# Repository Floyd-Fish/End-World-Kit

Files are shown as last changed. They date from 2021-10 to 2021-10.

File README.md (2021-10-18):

# End-World-Kit
末世生存装置——帮助你在废土世界中(比如核战争后的世界)更好地生存的传感器平台

## 安装的传感器

| 型号 | 描述 |
| ----- | --- |
| BMP280 | 温度、气压(可据此推算海拔) |
| SHT30D | 温度与湿度 |
| BH1750 | 数字光强度 |
| CCS811 | 二氧化碳与挥发性有机物 |
| MPU6050 | 6轴加速度与倾角传感器(附带温度) |
| S12SD | 紫外线强度 |
| [Open-Radiation-Detector](https://hackaday.io/project/27508-open-radiation-detector) | 辐射检测 |
| ATGM336H | 北斗+GPS双模定位模组(**未安装测试**) |

## 工程组织

原理图&PCB使用Kicad 5.1.9设计，4层板
软件使用Visual GDB+Arduino框架为ESP32开发，使用了很多第三方库

# English README

End World-Kit --- A sensor platform which makes your living more easier in the Wastland world (eg: a world after nuclear war)

## Sensors on board:

| Model | Description |
| ----- | --- |
| BMP280 | Temperature and Pressure (and altitude)|
| SHT30D | Temperature and Humidity |
| BH1750 | Digital Light (lux) |
| CCS811 | CO2 and TVOC |
| MPU6050 | 6-axis Gyro (and Temperature) |
| S12SD | UV Light Level |
| [Open-Radiation-Detector](https://hackaday.io/project/27508-open-radiation-detector) | Radiation Detect |
| ATGM336H | BD+GPS (**Not Tested yet**) |

## Project Structure

Schematic & PCB were designed using Kicad 5.1.9, 4-Layer PCB.

ESP32 was deved using Visual GDB & Arduino Framework, lots of 3rd-party libraries were used.

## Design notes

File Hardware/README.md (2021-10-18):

# Hardware

Developed by KiCad 5.1.9, Please Note it's not compatible with the newest KiCad Version 6.0.  

# Note

To save materials, I put 2 boards together so u need to cut them into 2 pieces.

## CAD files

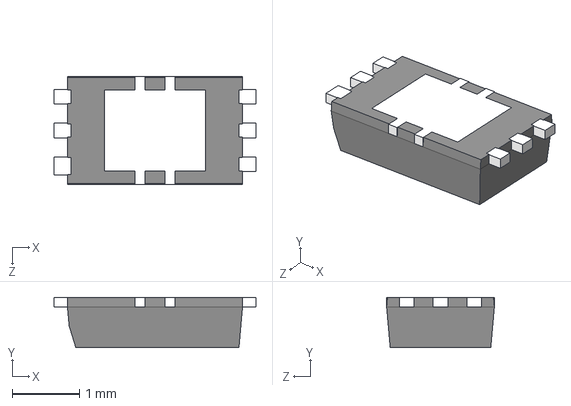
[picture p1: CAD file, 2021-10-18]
Hardware/End_World_Kit_V3.0/3D/BH1750FVI-TR.stp
3.00 x 0.75 x 1.60 mm

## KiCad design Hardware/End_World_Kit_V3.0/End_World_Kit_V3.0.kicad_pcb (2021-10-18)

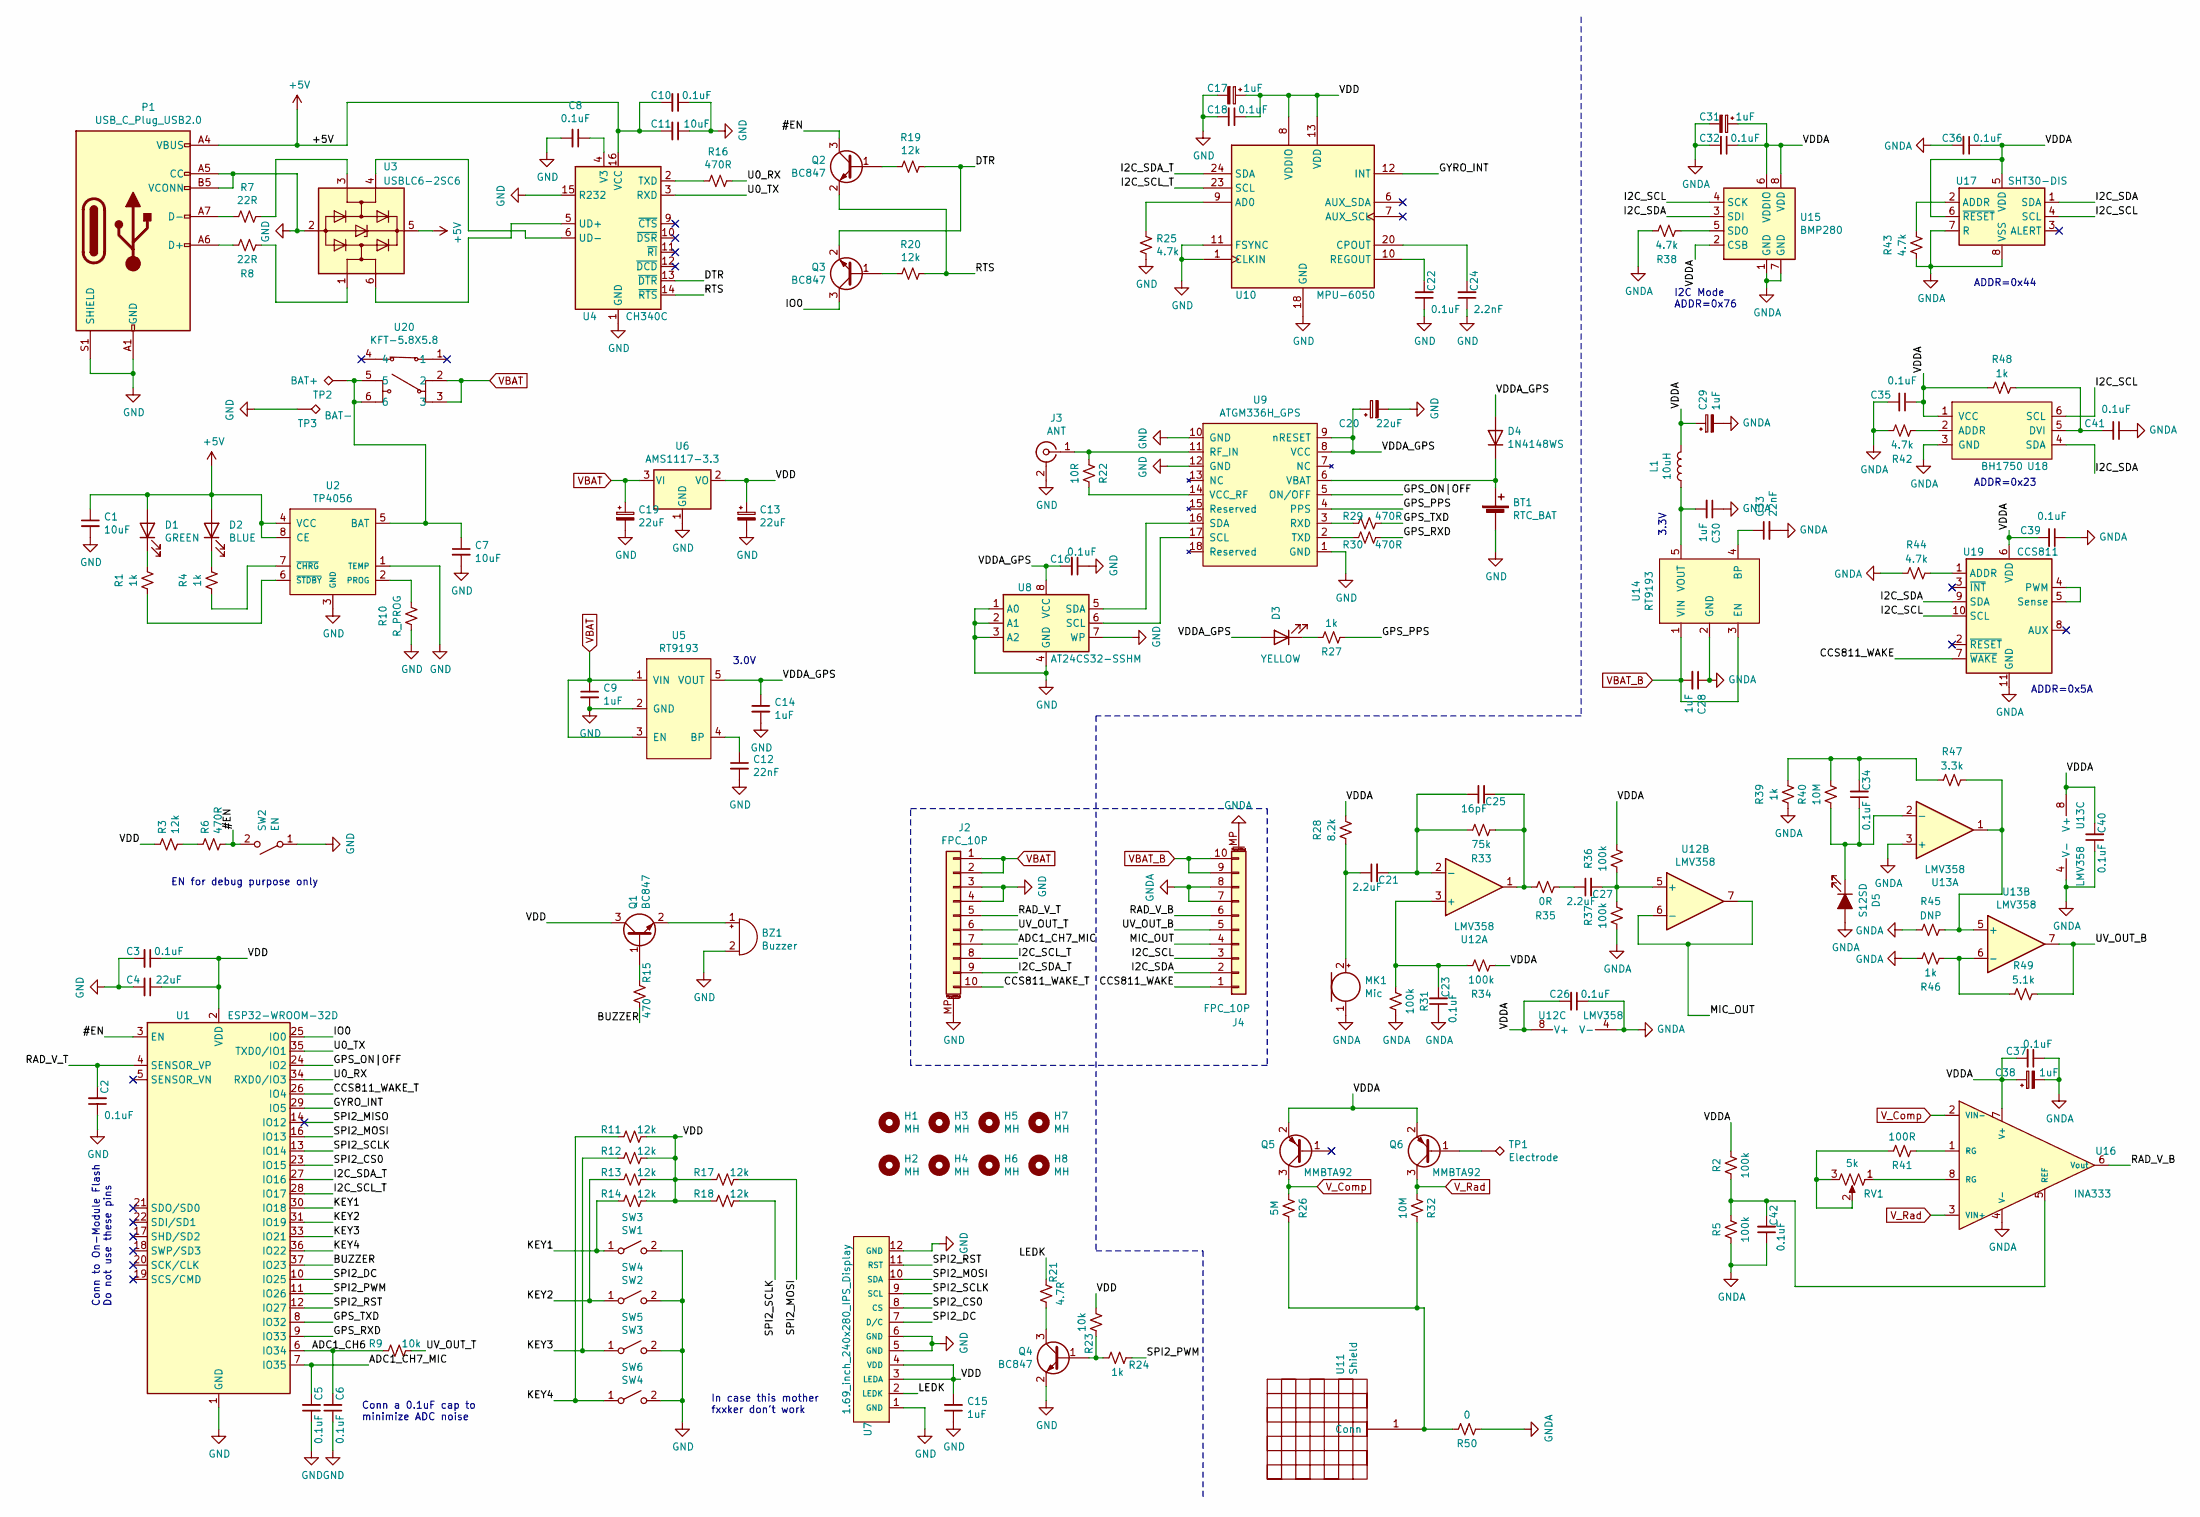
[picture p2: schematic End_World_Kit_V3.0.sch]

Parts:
BT1: RTC_BAT; XH414HG-IV01E
BZ1: Buzzer; 9032_BUZZER
C1, C7, C11: 10uF; C_0805_2012Metric
C2, C3, C5, C6, C8, C10, C16, C18, C22, C23, C26, C32, C34, C35, C36, C37, C39, C40, C41, C42: 0.1uF; C_0603_1608Metric
C4, C13, C19, C20: 22uF; CP_EIA-3528-15_AVX-H
C9, C14, C28, C30: 1uF; C_0805_2012Metric
C12, C33: 22nF; C_0603_1608Metric
C15: 1uF; C_0603_1608Metric
C17, C29, C31, C38: 1uF; CP_EIA-3216-12_Kemet-S
C21, C27: 2.2uF; C_0603_1608Metric
C24: 2.2nF; C_0603_1608Metric
C25: 16pF; C_0603_1608Metric
D1: GREEN; D_0805_2012Metric
D2: BLUE; D_0805_2012Metric
D3: YELLOW; D_0805_2012Metric
D4: 1N4148WS; D_SOD-323
D5: S12SD
H1, H2, H3, H4, H5, H6, H7, H8: MH; MountingHole_2.2mm_M2_Pad_Via
J2, J4: FPC_10P; TE_1-1734839-0_1x10-1MP_P0.5mm_Horizontal
J3: ANT; U.FL_Molex_MCRF_73412-0110_Vertical
L1: 10uH; L_1206_3216Metric
MK1: Mic; 4.5mmx2.2mm_Mic
P1: USB_C_Plug_USB2.0; USB_C_Receptacle_HRO_TYPE-C-31-M-12
Q1, Q2, Q3, Q4: BC847; SOT-23
Q5, Q6: MMBTA92; SOT-23
R1, R4, R24, R27, R39, R46, R48: 1k; R_0603_1608Metric
R2, R5, R31, R34, R36, R37: 100k; R_0603_1608Metric
R3, R11, R12, R13, R14, R17, R18, R19, R20: 12k; R_0603_1608Metric
R6, R16, R29, R30: 470R; R_0603_1608Metric
R7, R8: 22R; R_0603_1608Metric
R9, R23: 10k; R_0603_1608Metric
R10: R_PROG; R_0603_1608Metric
R15: 470; R_0603_1608Metric
R21: 4.7R; R_0805_2012Metric
R22: 10R; R_0603_1608Metric
R25, R38, R42, R43, R44: 4.7k; R_0603_1608Metric
R26: 5M; R_0805_2012Metric
R28: 8.2k; R_0603_1608Metric
R32: 10M; R_0805_2012Metric
R33: 75k; R_0603_1608Metric
R35: 0R; R_0603_1608Metric
R40: 10M; R_0603_1608Metric
R41: 100R; R_0603_1608Metric
R45: DNP; R_0603_1608Metric
R47: 3.3k; R_0603_1608Metric
R49: 5.1k; R_0603_1608Metric
R50: 0; R_0805_2012Metric
RV1: 5k; Potentiometer_Bourns_3214J_Horizontal
SW2: EN; turtle_little_3mmx4mm
SW3: SW1; TS-F010
SW4: SW2; TS-F010
SW5: SW3; TS-F010
SW6: SW4; TS-F010
TP1: Electrode; TestPoint_Pad_2.5x2.5mm
TP2: BAT+; TestPoint_Pad_2.5x2.5mm
TP3: BAT-; TestPoint_Pad_2.5x2.5mm
U1: ESP32-WROOM-32D; ESP32-WROOM-32
U2: TP4056; SOP-8_3.9x4.9mm_P1.27mm
U3: USBLC6-2SC6; SOT-23-6
U4: CH340C; SOIC-16_3.9x9.9mm_P1.27mm
U5, U14: RT9193; SOT-23-5
U6: AMS1117-3.3; SOT-223-3_TabPin2
U7: 1.69_inch_240x280_IPS_Display; ZJY169T-IG01
U8: AT24CS32-SSHM; SOIC-8_3.9x4.9mm_P1.27mm
U9: ATGM336H_GPS; ATGM336H-5N
U10: MPU-6050; InvenSense_QFN-24_4x4mm_P0.5mm
U11: Shield
U12, U13: LMV358; SOIC-8_3.9x4.9mm_P1.27mm
U15: BMP280; Bosch_LGA-8_2x2.5mm_P0.65mm_ClockwisePinNumbering
U16: INA333; VSSOP-8_3.0x3.0mm_P0.65mm
U17: SHT30-DIS; SHT3X
U18: BH1750
U19: CCS811; AMS_LGA-10-1EP_2.7x4mm_P0.6mm
U20: KFT-5.8X5.8; KFT-5.8x5.8

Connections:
+5V: C1.1, C10.2, C11.2, D1.2 (A), D2.2 (A), P1.A4 (VBUS), P1.A9 (VBUS), P1.B4 (VBUS), P1.B9 (VBUS), U2.4 (VCC), U2.8 (CE), U3.5 (VBUS), U4.16 (VCC)
/#EN: Q2.3 (C), R6.1, SW2.2 (B), U1.3 (EN)
/ADC1_CH6: C6.2, R9.2, U1.6 (IO34)
/ADC1_CH7_MIC: C5.2, J2.7, U1.7 (IO35)
/BUZZER: R15.1, U1.37 (IO23)
/CCS811_WAKE: J4.1, U19.7 (~WAKE)
/CCS811_WAKE_T: J2.10, U1.26 (IO4)
/DTR: Q3.2 (E), R19.1, U4.13 (~DTR)
/GPS_ON|OFF: U1.24 (IO2), U9.5 (ON/OFF)
/GPS_PPS: R27.2, U9.4 (PPS)
/GPS_RXD: R30.2, U1.9 (IO33)
/GPS_TXD: R29.2, U1.8 (IO32)
/GYRO_INT: U1.29 (IO5), U10.12 (INT)
/I2C_SCL: J4.3, U15.4 (SCK), U17.4 (SCL), U18.6 (SCL), U19.10 (SCL)
/I2C_SCL_T: J2.8, U1.28 (IO17), U10.23 (SCL)
/I2C_SDA: J4.2, U15.3 (SDI), U17.1 (SDA), U18.4 (SDA), U19.9 (SDA)
/I2C_SDA_T: J2.9, U1.27 (IO16), U10.24 (SDA)
/IO0: Q3.3 (C), U1.25 (IO0)
/KEY1: R14.2, SW3.1 (A), U1.30 (IO18)
/KEY2: R13.2, SW4.1 (A), U1.31 (IO19)
/KEY3: R12.2, SW5.1 (A), U1.33 (IO21)
/KEY4: R11.2, SW6.1 (A), U1.36 (IO22)
/LEDK: R21.2, U7.2 (LEDK)
/MIC_OUT: J4.4, U12.6 (-), U12.7
/RAD_V_B: J4.6, U16.6 (Vout)
/RAD_V_T: C2.2, J2.5, U1.4 (SENSOR_VP)
/RTS: Q2.2 (E), R20.1, U4.14 (~RTS)
/SPI2_CS0: U1.23 (IO15), U7.8 (CS)
/SPI2_DC: U1.10 (IO25), U7.7 (D/C)
/SPI2_MOSI: R17.1, U1.16 (IO13), U7.10 (SDA)
/SPI2_PWM: R24.2, U1.11 (IO26)
/SPI2_RST: U1.12 (IO27), U7.11 (RST)
/SPI2_SCLK: R18.1, U1.13 (IO14), U7.9 (SCL)
/U0_RX: R16.1, U1.34 (RXD0/IO3)
/U0_TX: U1.35 (TXD0/IO1), U4.3 (RXD)
/UV_OUT_B: J4.5, R49.1, U13.7
/UV_OUT_T: J2.6, R9.1
/VDD: C3.1, C4.1, C13.1, C15.2, C17.1, C18.1, Q1.3 (C), R3.1, R11.1, R12.1, R13.1, R14.1, R17.2, R18.2, R23.1, U1.2 (VDD), U6.2 (VO), U7.3 (LEDA), U7.4 (VDD), U10.8 (VDDIO), U10.13 (VDD)
/VDDA: C26.2, C29.1, C31.1, C32.1, C35.1, C36.1, C37.2, C38.1, C39.2, C40.2, L1.2, Q5.2 (E), Q6.2 (E), R2.2, R28.1, R34.2, R36.1, R48.2, U12.8 (V+), U13.8 (V+), U15.2 (CSB), U15.6 (VDDIO), U15.8 (VDD), U16.7 (V+), U17.5 (VDD), U17.6 (~RESET), U18.1 (VCC), U19.6 (VDD)
/VDDA_GPS: C14.1, C16.2, C20.1, D3.2 (A), D4.2 (A), U5.5 (VOUT), U8.8 (VCC), U9.8 (VCC), U9.9 (nRESET)
GND: BT1.2 (-), BZ1.2 (+), C1.2, C2.1, C3.2, C4.2, C5.1, C6.1, C7.2, C8.2, C9.2, C10.1, C11.1, C12.2, C13.2, C14.2, C15.1, C16.1, C17.2, C18.2, C19.2, C20.2, C22.1, C24.1, J2.3, J2.4, J2.MP (MountPin), J3.2 (Ext), P1.A1 (GND), P1.A5 (CC), P1.A12 (GND), P1.B1 (GND), P1.B5 (VCONN), P1.B12 (GND), P1.S1 (SHIELD), Q4.2 (E), R10.1, R25.1, SW2.1 (A), SW3.2 (B), SW4.2 (B), SW5.2 (B), SW6.2 (B), TP3.1, U1.1 (GND), U1.15 (GND), U1.38 (GND), U1.39 (GND), U2.1 (TEMP), U2.3 (GND), U3.2 (GND), U4.1 (GND), U4.15 (R232), U5.2 (GND), U6.1 (GND), U7.1 (GND), U7.5 (GND), U7.6 (GND), U7.12 (GND), U8.1 (A0), U8.2 (A1), U8.3 (A2), U8.4 (GND), U8.7 (WP), U9.1 (GND), U9.10 (GND), U9.12 (GND), U10.1 (CLKIN), U10.11 (FSYNC), U10.18 (GND)
GNDA: C23.1, C26.1, C28.1, C29.2, C30.1, C31.2, C32.2, C33.2, C35.2, C36.2, C37.1, C38.2, C39.1, C40.1, C41.1, C42.1, D5.2 (A), J4.7, J4.8, J4.MP (MountPin), MK1.1 (-), R5.1, R31.1, R37.2, R38.2, R39.1, R42.1, R43.1, R44.2, R45.2, R46.1, R50.1, U12.4 (V-), U13.3 (+), U13.4 (V-), U14.2 (GND), U15.1 (GND), U15.7 (GND), U16.4 (V-), U17.7 (R), U17.8 (VSS), U17.9 (VSS), U18.3 (GND), U19.11 (GND)
unnamed: BT1.1 (+), D4.1 (K), U9.6 (VBAT)
unnamed: BZ1.1 (-), Q1.2 (E)
unnamed: C7.1, TP2.1, U2.5 (BAT), U20.5, U20.6
unnamed: C8.1, U4.4 (V3)
unnamed: C12.1, U5.4 (BP)
unnamed: C21.1, MK1.2 (+), R28.2
unnamed: C21.2, C25.1, R33.1, U12.2 (-)
unnamed: C22.2, U10.10 (REGOUT)
unnamed: C23.2, R31.2, R34.1, U12.3 (+)
unnamed: C24.2, U10.20 (CPOUT)
unnamed: C25.2, R33.2, R35.1, U12.1
unnamed: C27.1, R35.2
unnamed: C27.2, R36.2, R37.1, U12.5 (+)
unnamed: C30.2, L1.1, U14.5 (VOUT)
unnamed: C33.1, U14.4 (BP)
unnamed: C34.1, D5.1 (K), R40.2, U13.2 (-)
unnamed: C34.2, R39.2, R40.1, R47.1
unnamed: C41.2, R48.1, U18.5 (DVI)
unnamed: C42.2, R2.1, R5.2, U16.5 (REF)
unnamed: D1.1 (K), R1.2
unnamed: D2.1 (K), R4.2
unnamed: D3.1 (K), R27.1
unnamed: J3.1 (In), R22.2, U9.11 (RF_IN)
unnamed: P1.A6 (D+), R8.2
unnamed: P1.A7 (D-), R7.2
unnamed: Q1.1 (B), R15.2
unnamed: Q2.1 (B), R19.2
unnamed: Q3.1 (B), R20.2
unnamed: Q4.1 (B), R23.2, R24.1
unnamed: Q4.3 (C), R21.1
unnamed: Q6.1 (B), TP1.1
unnamed: R1.1, U2.6 (~STDBY)
unnamed: R3.2, R6.2
unnamed: R4.1, U2.7 (~CHRG)
unnamed: R7.1, U3.3 (I/O2)
unnamed: R8.1, U3.1 (I/O1)
unnamed: R10.2, U2.2 (PROG)
unnamed: R16.2, U4.2 (TXD)
unnamed: R22.1, U9.14 (VCC_RF)
unnamed: R25.2, U10.9 (AD0)
unnamed: R26.2, R32.2, R50.2, U11.1
unnamed: R29.1, U9.3 (RXD)
unnamed: R30.1, U9.2 (TXD)
unnamed: R38.1, U15.5 (SDO)
unnamed: R41.1, U16.1 (RG)
unnamed: R41.2, RV1.2, RV1.3
unnamed: R42.2, U18.2 (ADDR)
unnamed: R43.2, U17.2 (ADDR)
unnamed: R44.1, U19.1 (ADDR)
unnamed: R45.1, R47.2, U13.1, U13.5 (+)
unnamed: R46.2, R49.2, U13.6 (-)
unnamed: RV1.1, U16.8 (RG)
unnamed: U3.4 (I/O2), U4.6 (UD-)
unnamed: U3.6 (I/O1), U4.5 (UD+)
unnamed: U8.5 (SDA), U9.16 (SDA)
unnamed: U8.6 (SCL), U9.17 (SCL)
unnamed: U19.4 (PWM), U19.5 (Sense)
VBAT: C9.1, C19.1, J2.1, J2.2, U5.1 (VIN), U5.3 (EN), U6.3 (VI), U20.2, U20.3
VBAT_B: C28.2, J4.9, J4.10, U14.1 (VIN), U14.3 (EN)
V_Comp: Q5.3 (C), R26.1, U16.2 (VIN-)
V_Rad: Q6.3 (C), R32.1, U16.3 (VIN+)

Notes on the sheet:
In case this mother fxxker don't work
Conn a 0.1uF cap to minimize ADC noise
EN for debug purpose only
Conn to On-Module Flash Do not use these pins
I2C Mode ADDR=0x76
ADDR=0x44
ADDR=0x23
ADDR=0x5A
3.0V
3.3V

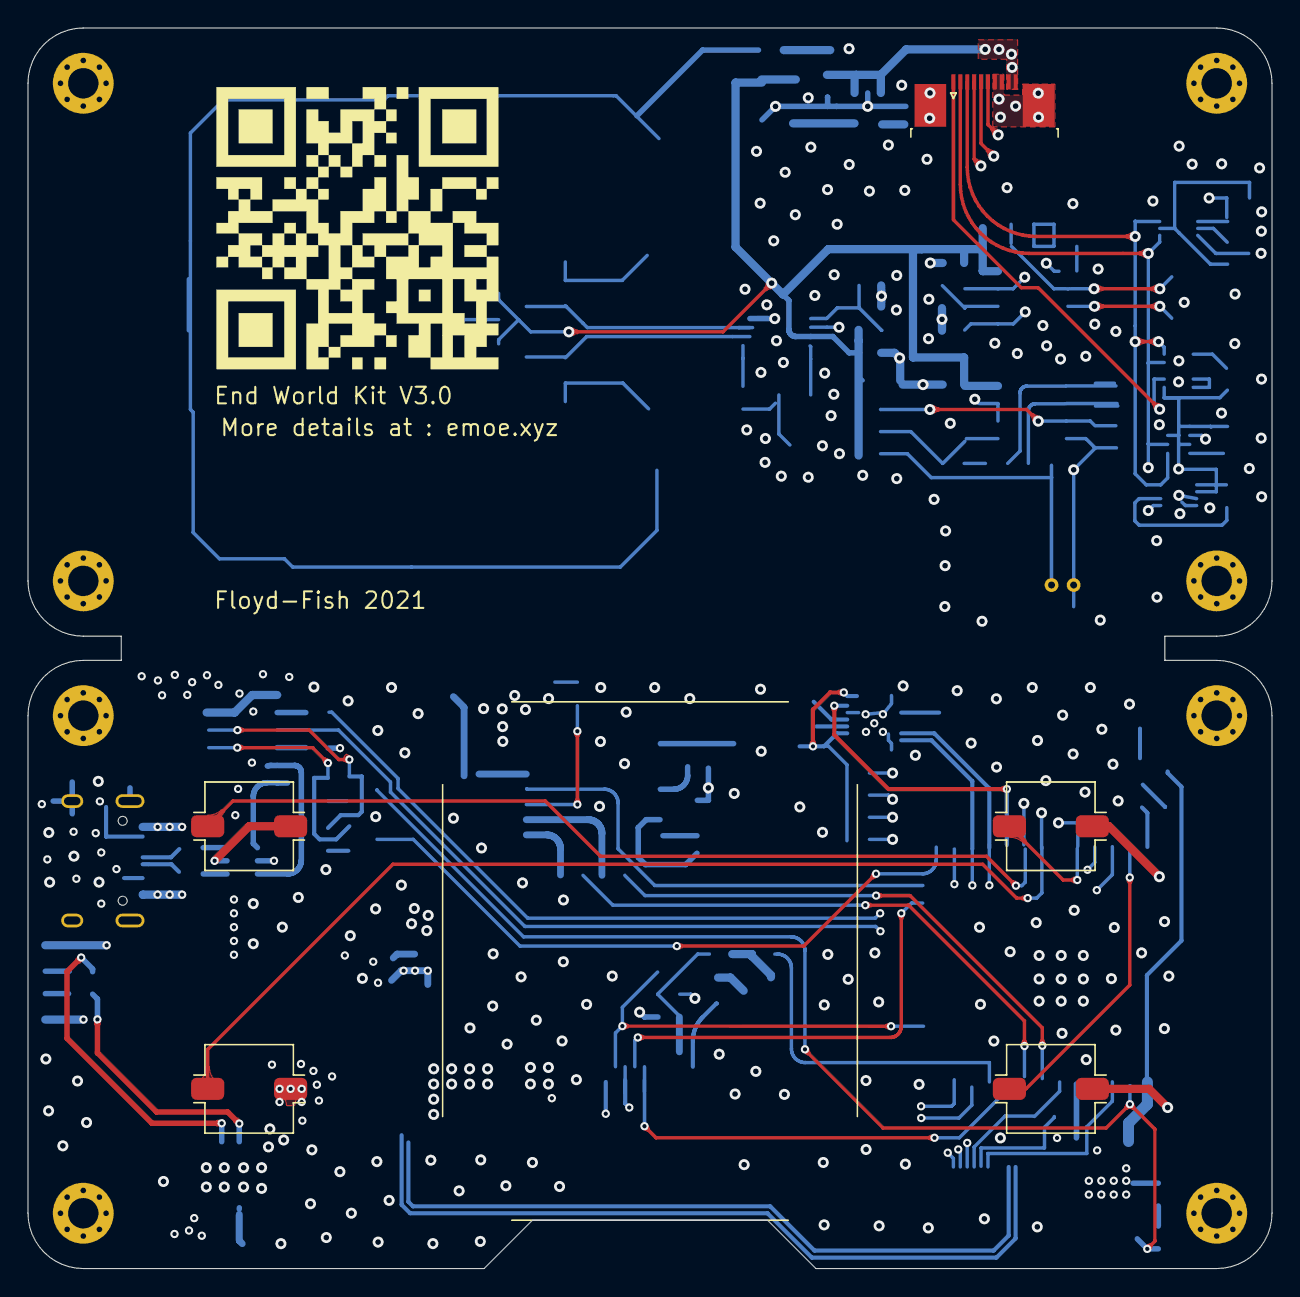
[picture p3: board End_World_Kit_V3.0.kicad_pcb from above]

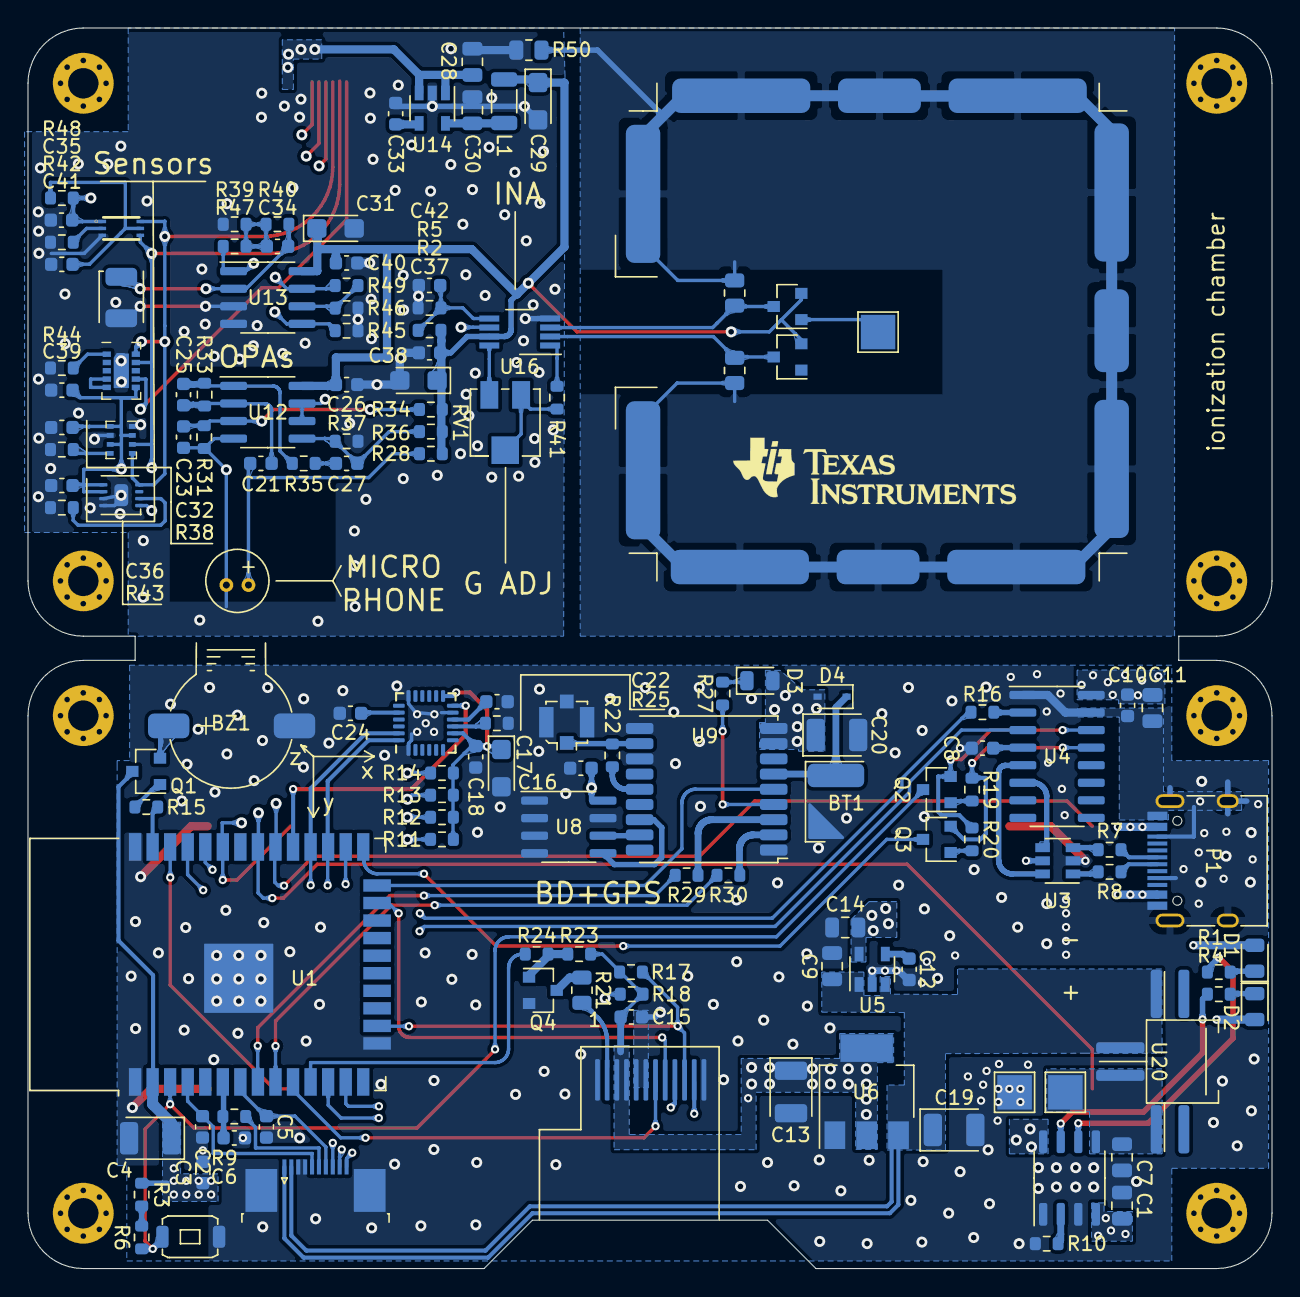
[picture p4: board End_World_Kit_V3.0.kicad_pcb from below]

Board: 4 copper layers, 90.0 x 89.8 mm, 148 parts (134 on the bottom side), 103 nets.
